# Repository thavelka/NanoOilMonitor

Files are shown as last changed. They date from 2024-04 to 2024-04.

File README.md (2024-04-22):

# NanoOilMonitor
Sketch to monitor oil temp and pressure and write to 128x64 OLED display.  
Also includes STL files for display/button housing and a board housing for the arduino. 

https://github.com/thavelka/NanoOilMonitor/assets/8907132/da23afdf-3d59-4e5f-9234-c822fb60fd93

# Applications
I am using this in a 2016 Mazda MX-5. You can use this in any vehicle with provisions for oil sensors. You can purchase a [sandwich plate](https://www.amazon.com/GlowShift-Filter-Sandwich-Adapter-Thread/dp/B007SXGAZQ) for your vehicle if you do not have ports you can tap into. I am using a sandwich plate that was included with my oil cooler.

Recommended temperatures and pressures may be different for your vehicle. Check your factory service manual for the correct values and update the constants in the sketch.

# Components
* [1.3 in SPI OLED](https://www.microcenter.com/product/643965/inland-iic-spi-13-128x64-oled-v20-graphic-display-module-for-arduino-uno-r3) (~$8 from MC or Amazon)
* [Arduino Nano](https://www.microcenter.com/product/615097/inland-nano-development-board-arduino-compatible) ($5-10 from MC or Amazon)
* [NTC Temp Sensor](https://www.mlperformanceusa.com/products/canchecked-cc22902-ntc-temperature-sensor-1-8-npt-thread-for-oil-water) ($30, get a good one)
* [5v pressure Sensor](https://www.amazon.com/Universal-Pressure-Transducer-Sender-Connector/dp/B09VRDM71G) ($16)
* [Momentary push button](https://www.amazon.com/Cylewet-Momentary-Button-Switch-CYT1078/dp/B0752RMB7Q) (for mode select)
* [3 conductor cable for sensors](https://www.amazon.com/gp/product/B0B7L1TQ33) ($15)
* 8 conductor cable for display and button (ethernet cable works)
* 5v source (e.g. [Dashcam hardwire kit](https://www.amazon.com/Hardwire-Dashcam-Camera-Charger-%EF%BC%8813ft%EF%BC%89/dp/B07YBDMD8V) or buck converter, L7805, etc.)

Total cost: $80-100

# Hookup
```
5v source: VIN  
Ground: GND  

Temp sensor positive: A4  
Temp sensor output: A6  
Temp sensor ground: GND  

Pressure sensor positive: A5  
Pressure sensor output: A7  
Pressure sensor ground: GND  

Momentary button: A3, GND  

Display VCC: 5V  
Display GND: GND  
Display MOSI: D11  
Display CLK: D13  
Display CS: A0  
Display DC: A1  
Display RES: A2
```
Run the ethernet cable through the back of the display housing and solder to the display.  
Install the button in the back of the display housing. Solder one leg to the remaining wire on the ethernet cable and the other leg to the ground wire in the ethernet cable.

# Usage
Press button to cycle mode
#### Modes
1. Standby (default) - Display for 10 seconds then go dark unless alert thresholds exceeded.
2. Unit - Display temp in degrees F and pressure in PSI
3. Idiot light - Display temp ranges (COLD, COOL, OK, HOT), pressure ranges (ALERT, LOW, OK, HIGH).

# Improvements
* You could compact this into just the display housing if you used an ATTiny and moved the voltage regulation outside the unit. You would want to use an I2C display instead of SPI.
* I used screw terminal blocks for this prototype since I had them, but I would recommend JST connectors or soldering instead for motorsports usage.

# Photos






# Credit
* Orignal display housing: https://www.thingiverse.com/thing:4680559
* Display lib: https://github.com/olikraus/u8g2

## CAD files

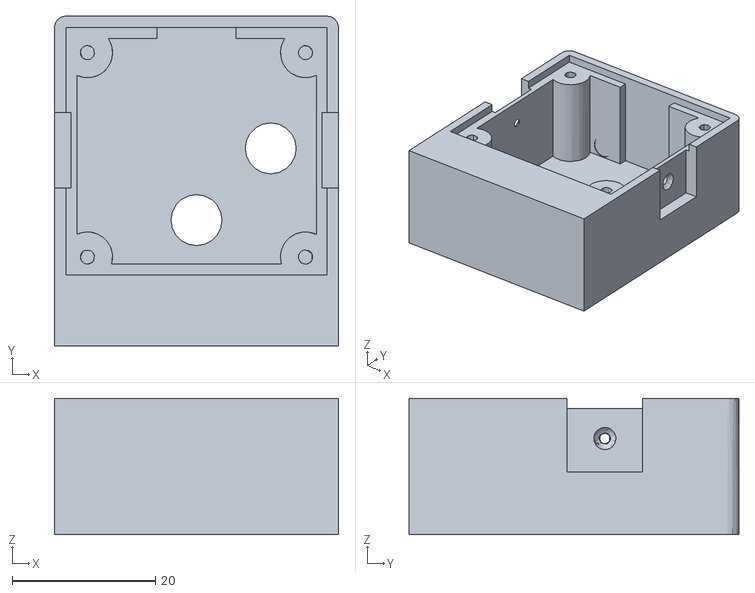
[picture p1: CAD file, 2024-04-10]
displayhousing.stl
39.6 x 46.0 x 19.0

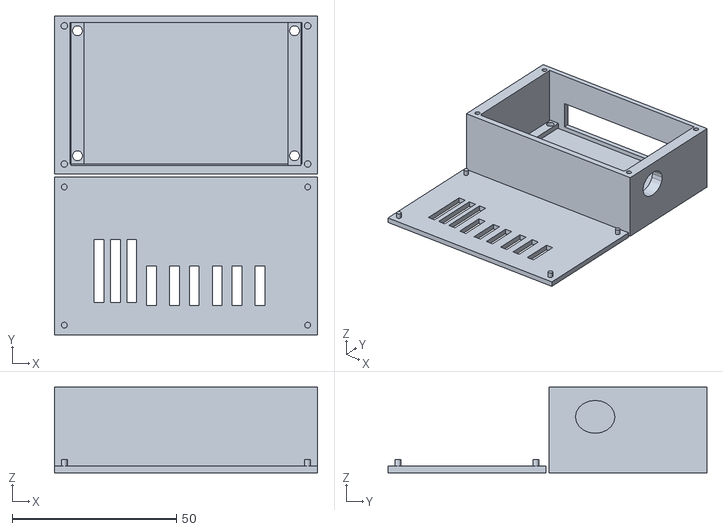
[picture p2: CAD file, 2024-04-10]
boardhousing.stl
80.0 x 97.0 x 26.0

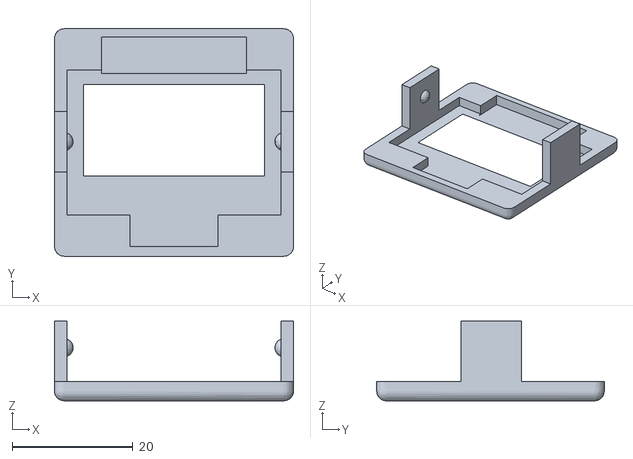
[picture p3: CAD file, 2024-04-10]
displaycover.stl
39.6 x 37.7 x 13.2

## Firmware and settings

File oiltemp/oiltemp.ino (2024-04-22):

#include <Arduino.h>
#include <U8g2lib.h>
#include <SPI.h>
#include <Wire.h>

// Declare pins
const int tempInputPin = A6;
const int pressureInputPin = A7;
const int tempPowerOut = A4;
const int pressurePowerOut = A5;
const int modeSwitch = A3;
const int res = A2;
const int DC = A1;
const int CS = A0;

//============================================================================
// Constants - configure for your vehicle and sensors
//============================================================================
const bool demoMode = false; // Set true to sweep values

const long tempPullUpOhms = 1000;
const long maxAnalogVal = 1024; // Highest possible value from analog input

// Temp sensor config, map temp in C to expected ohms, from datasheet
const int arrSize = 12;
const int temps[12] = {40, 50, 60, 70, 80, 90, 100, 110, 120, 130, 140, 150}; // In deg C
const int thresholds[12] = {925, 630, 438, 315, 224, 163, 120, 90, 80, 70, 50, 40}; // In ohms

// Pressure sensor config, from datasheet
const int pressureBaseVal = 102; // Analog value at 0 PSI (0.5 V)
const int pressureMaxVal = 922; // Analog value at max pressure (4.5 V)
const int pressureMaxPsi = 100; // Pressure in PSI at pressureMaxVal

// Display config
const int reportIntervalMillis = 1000; // How often the screen should update under nominal conditions
const int standbyMillis = 10000; // Go blank after this time unless alert
const int clickDebounceMillis = 500;

// Temp alert preferences
const int tempColdF = 104; // "Cold" shown below this temp
const int tempCoolF = 150; // "Cool" shown below this temp
const int tempHighAlertF = 280; // "HOT" flashes above this temp

// Pressure alert preferences
const int pressureLowAlertPsi = 15; // "ALERT" flashes below this value
const int pressureLowPsi = 35; // "LOW" shown below this value
const int pressureHighPsi = 85; // "HIGH" shown above this value

//============================================================================
// End Constants
//============================================================================

// Mode variables
enum Mode {STANDBY, UNITF, IDIOT, RAW};
int mode = STANDBY; // initial mode
long lastClickTimeMillis = 0;
long lastReportTimeMillis = 0;
bool alerting = false;

// Sample data buffers
int tempSamples[10] = {0, 0, 0, 0, 0, 0, 0, 0, 0, 0};
int currTempSampleIndex = 0;

// Configure display for 4 wire SPI
U8G2_SH1106_128X64_NONAME_F_4W_HW_SPI u8g2(U8G2_R0, /* cs=*/ CS, /* dc=*/ DC, /* reset=*/ res);

void setup() {
  pinMode(tempPowerOut, OUTPUT);
  pinMode(pressurePowerOut, OUTPUT);
  pinMode(modeSwitch, INPUT_PULLUP);

  Serial.begin(9600);
  u8g2.begin();

  // Fill buffers with initial data
  initTempSample();
}

void loop() {
  processClick();
  processData();
}

void processData() {
  // Get data for display
  float tempF = getTempF();
  float pressurePsi = getPressurePsi();

  // Update display if in alert mode or if reporting interval has lapsed
  alerting = isAlert(tempF, pressurePsi);
  if (!alerting && (millis() - lastReportTimeMillis < reportIntervalMillis)) {
    return; // Don't report
  } else {
    lastReportTimeMillis = millis();
  }

  // Write to screen
  switch (mode) {
    case STANDBY:
      drawStandbyMode(tempF, pressurePsi);
      break;
    case UNITF:
      drawUnitText(tempF, pressurePsi);
      break;
    case IDIOT:
      drawIdiotText(tempF, pressurePsi);
      break;
    case RAW:
      drawRawText();
      break;
  }
}

/** Return temp for display */
float getTempF() {
  if (demoMode) {
    return ((millis()/1000) % 10 + 1) * 30; // Demo loop 10 to 300
  } else {
    int tempValue = getSpotAverageTempValue();
    float resistance = getOhmicValue(tempValue);
    int tempC = getTempC(resistance);
    float tempF = cToF(tempC);
    return tempF;
  }
}

/** Return pressure for display */
float getPressurePsi() {
  if (demoMode) {
    return ((millis()/1000) % 10 + 1) * 10; // Demo loop 10 to 100
  } else {
    float pressureValue = getSpotAveragePressureValue();
    float pressurePsi = pressureValueToPsi(pressureValue);
    return pressurePsi;
  }
}

/** Prevents noisy reporting on threshold border */
int getMovingAverageTempValue() {
  sampleTemp(); 
  int sum = 0;
  for (int i = 0; i < 10; i++) {
    sum += tempSamples[i];
  }
  return sum / 10;
}

/** Update one value of temp sample buffer with most recent spot average */
void sampleTemp() {
  int tempValue = getSpotAverageTempValue();
  tempSamples[currTempSampleIndex] = tempValue;
  currTempSampleIndex = (currTempSampleIndex + 1) % 10;
}

/** Fill temp sample buffer */
void initTempSample() {
  sampleTemp();
  while (currTempSampleIndex != 0) {
    sampleTemp();
  }
}

/** Returns average pressure (out of 1024) over 50 ms */
int getSpotAveragePressureValue() {
  digitalWrite(pressurePowerOut, 1);
  delay(5);
  long sum = 0;
  for (int i = 0; i < 10; i++) {
    sum += analogRead(pressureInputPin);
  }
  digitalWrite(pressurePowerOut, 0);
  return sum / 10;
}

void clearScreen() {
  u8g2.firstPage();
  do {} while ( u8g2.nextPage() );
}

/* Blank screen after standby period unless in alert mode */
void drawStandbyMode(int temp, int pressure) {
  if (millis() < standbyMillis || alerting) {
    drawIdiotText(temp, pressure);
  } else {
    clearScreen();
  }
}

void drawUnitText(int tempF, int pressurePsi) {
  u8g2.firstPage();
  do {
    u8g2.setFont(u8g2_font_fub20_tr);
    
    // Print temp
    u8g2.setCursor(0, 32);
    u8g2.print("T: ");
    if (tempF < cToF(temps[0])) {
       u8g2.print("COLD"); // Show COLD below minimum value
    } else if (tempF < tempHighAlertF || (millis() / 100) % 2 == 0) { // Flash alert if not nominal
      char str[32];
      snprintf(str, 32, "%d F", (int)tempF);
      u8g2.print(str);
    }

    // Print pressure
    u8g2.setCursor(0, 60);
    u8g2.print("P: ");
    
    if (pressurePsi > pressureLowAlertPsi || (millis() / 100) % 2 == 0) { // Flash alert if not nominal
        u8g2.print(pressurePsi);
        u8g2.print(" PSI"); 
    }
    
  } while ( u8g2.nextPage() );
}

void drawIdiotText(int tempF, int pressurePsi) {
  u8g2.firstPage();
  do {
    u8g2.setFont(u8g2_font_fub20_tr);

    // Print temp
    u8g2.setCursor(0, 32);
    u8g2.print("T: ");
    if (tempF < tempColdF) {
      u8g2.print("COLD");  
    } else if (tempF < tempCoolF) {
      u8g2.print("COOL");
    } else if (tempF >= tempHighAlertF) {
      // Flash alert
      if ((millis() / 100) % 2 == 0) {
        u8g2.print("HOT");  
      }
    } else {
      u8g2.print("OK");
    }
  
  // Print pressure
    u8g2.setCursor(0, 60);
    u8g2.print("P: ");
    if (pressurePsi < pressureLowAlertPsi) {
      // Flash alert
      if ((millis() / 100) % 2 == 0) {
        u8g2.print("ALERT");  
      }
    } else if (pressurePsi < pressureLowPsi) {
      u8g2.print("LOW");  
    } else if (pressurePsi > pressureHighPsi) {
      u8g2.print("HIGH");
    } else {
      u8g2.print("OK");
    }
  } while ( u8g2.nextPage() );
}

void drawRawText() {
  u8g2.firstPage();
  do {
    u8g2.setFont(u8g2_font_fub20_tr);
    
    // Print temp
    u8g2.setCursor(0, 32);
    u8g2.print("T: ");
    u8g2.print(getSpotAverageTempValue());

    // Print pressure
    u8g2.setCursor(0, 60);
    u8g2.print("P: ");
    u8g2.print(getSpotAveragePressureValue());
    
  } while ( u8g2.nextPage() );
}

/** Returns average temp value (out of 1024) over 50 ms */
int getSpotAverageTempValue() {
  digitalWrite(tempPowerOut, 1);
  delay(5);
  long sum = 0;
  for (int i = 0; i < 10; i++) {
    sum += analogRead(tempInputPin);
  }
  digitalWrite(tempPowerOut, 0);
  return sum / 10;
}

/** Convert analog value (out of 1024) to ohms */
float getOhmicValue(long digitalValue) {
  long numerator = tempPullUpOhms * digitalValue;
  long denominator = maxAnalogVal - digitalValue;
  return ((float)numerator)/((float)denominator);
}

/** Convert ohms to temp in C using lookup table */
int getTempC(float ohms) {
  if (ohms > thresholds[0]) {
    return 0;
  }
  for (int i = 1; i < arrSize; i++) {
    if (ohms > thresholds[i]) {
      return temps[i - 1];
    }
  }
  
  return temps[arrSize - 1]; // Max temp
}

/** Convert analog pressure value (out of 1024) to PSI */
float pressureValueToPsi(int pressureValue) {
  int range = pressureMaxVal - pressureBaseVal;
  int adjustedValue = pressureValue - pressureBaseVal;
  float psi = (((float) adjustedValue) / ((float) range)) * pressureMaxPsi;
  return psi;
}

float cToF(float tempC) {
  return ((tempC * 9.0) / 5.0) + 32.0;
}

void processClick() {
  bool clicked = !digitalRead(modeSwitch);
  if (clicked) {
    long currTime = millis();
    if (currTime - lastClickTimeMillis > clickDebounceMillis) {
      lastClickTimeMillis = currTime;
      switchMode();
    }
  }
}

/** Cycles to next mode */
void switchMode() {
  mode = (mode + 1) % 3;
  lastReportTimeMillis = 0; // Report immediately
}

/** Returns true if temp exceeds alert threshold or pressure falls below alert threshold */
bool isAlert(int tempF, int pressurePsi) {
  return tempF > tempHighAlertF || pressurePsi < pressureLowAlertPsi;
}

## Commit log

2024-04-10 Add 3d print files
    [boardhousing.stl, displaycover.stl, displayhousing.stl]
2024-04-22 Change sensor pressure max to 100psi
